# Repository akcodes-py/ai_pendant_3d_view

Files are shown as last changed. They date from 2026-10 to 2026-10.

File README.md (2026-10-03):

# Brain2 AI Pendant - 3D Interactive Web Viewer & CAD Architecture

An interactive, high-fidelity 3D web viewer and parametric CAD assembly model for the **Brain2 Wearable AI Pendant** prototype built with an octagonal cardboard enclosure and a 3-tier Starboard (perfboard) stacked core.

🌐 **Live 3D Web Viewer**: [https://akcodes-py.github.io/ai_pendant_3d_view/](https://akcodes-py.github.io/ai_pendant_3d_view/)  
📁 **Local File**: Open [`ai_pendant_3d_viewer.html`](ai_pendant_3d_viewer.html) or [`index.html`](index.html) in any browser.

---

## 🌟 Key Features

- **Realistic Electronic Component Rendering**:
  - **ESP32-S3 DevKit**: Rendered with dark PCB traces, gold header pins, silver metal RF shield, micro-USB connector, and silkscreen markings.
  - **INMP441 I2S MEMS Microphone**: Purple PCB with golden circular acoustic MEMS port positioned on the **upper side** facing the front sound pinhole for crystal-clear voice pickup.
  - **MicroSD Card Adapter**: Deep blue PCB, stainless-steel push-push card socket, and partially inserted microSD card facing the side cutout for easy card swapping.
  - **MT3608 5V Step-Up Boost Converter**: Rendered with copper toroidal ferrite inductor coil and precision multi-turn trimmer potentiometer.
  - **TP4056 Battery Charger**: Blue PCB with USB-C connector facing the side wall cutout.
  - **800mAh Li-Po Battery**: Silver metallic vacuum-sealed pouch cell with yellow Kapton insulation tape and silicone power lead wires.
  - **Starboard Perfboards**: Double-sided gold donut solder pads at standard $2.54\text{ mm}$ pitch.
- **Dual Front Controls & Indicator**:
  1. **5mm Blue Indicator LED**: Located at upper-center ($Y=72\text{ mm}$).
  2. **Round Voice Push Button Switch**: Located at mid-center ($Y=46\text{ mm}$) for thumb voice recording trigger.
  3. **White Push-Push Latching Power Switch**: Located at lower-center ($Y=24\text{ mm}$). Features white nylon stepped collar, round plunger, and dual horizontal solder tabs. Latches down on click (ON) and springs up on click (OFF) to cut battery power.
  4. **Upper-Side Microphone Sound Pinhole**: Located on the top-left shoulder ($Y=74\text{ mm}$) with golden bezel ring.
- **Interactive Controls Simulator**:
  - **Click White Power Switch**: Plunger physically latches down in 3D (ON) and energizes the circuit & Blue LED; clicking again pops it up (OFF) and cuts power.
  - **Press Voice Button**: Depresses the 3D button and activates **`RECORDING AUDIO`** mode with a pulsing Blue LED.
- **Vertical Layer Explosion Slider**:
  - Drag the slider from $0\text{ mm}$ (fully assembled) to $75\text{ mm}$ (exploded view) to pull apart all 3 Starboard decks and cardboard covers in mid-air.
- **Layer Isolation Filtering**:
  - Isolate and inspect any individual plate or starboard deck with zero clutter.

---

## 📐 Measured Component Dimensions (Hand Scale)

| Component Name | Length (cm) | Breadth (cm) | Height (cm) | Converted ($L \times W \times H$) | Stack Deck |
| :--- | :---: | :---: | :---: | :---: | :--- |
| **INMP441 MEMS Mic** | 1.4 | 1.1 | 0.35 | **$14 \times 11 \times 3.5\text{ mm}$** | **Deck 1 (Top / Front)** |
| **MicroSD Card Adapter** | 5.0 | 2.5 | 1.0 | **$50 \times 25 \times 10\text{ mm}$** | **Deck 1 (Top / Front)** |
| **ESP32-S3 DevKit** | 7.0 | 3.9 | 1.0 | **$70 \times 39 \times 10\text{ mm}$** | **Deck 2 (Middle)** |
| **Boost Converter (3V→5V)** | 4.5 | 2.3 | 1.5 | **$45 \times 23 \times 15\text{ mm}$** | **Deck 3 (Bottom / Power)** |
| **TP4056 Battery Charger** | 3.0 | 1.8 | 0.3 | **$30 \times 18 \times 3\text{ mm}$** | **Deck 3 (Bottom / Power)** |
| **800mAh Li-Po Battery** | 3.7 | 2.5 | 0.5 | **$37 \times 25 \times 5\text{ mm}$** | **Deck 3 (Bottom / Power)** |
| **White Latching Switch** | 0.8 | 0.8 | 0.7 | **$8 \times 8 \times 7\text{ mm}$** | **Deck 1 (Front Power)** |
| **Front Controls** | — | — | — | **$\varnothing 5\text{mm}$ LED, $\varnothing 7\text{mm}$ Button** | **Front Faceplate** |

---

## 🏗️ 3-Starboard Stack Architecture

```
┌────────────────────────────────────────────────────────┐
│  PLATE 1: FRONT CARDBOARD FACEPLATE (2.0 mm)           │
│  - Hole 1: 5mm Blue LED Dome (Ø5.0 mm at Y=72)         │
│  - Hole 2: Round Voice Push Button Cap (Ø7.0 mm at Y=46)│
│  - Hole 3: White Latching Switch Opening (Ø5.8 mm, Y=24)│
│  - Hole 4: Upper-Side Mic Sound Pinhole (Ø1.8 mm)      │
└────────────────────────────────────────────────────────┘
                           │
┌────────────────────────────────────────────────────────┐
│  PLATE 2: STARBOARD 1 (FRONT DECK: MIC + SD + CONTROLS)│
│  - INMP441 MEMS Mic on UPPER SIDE facing front hole    │
│  - MicroSD Card Adapter (50 × 25 × 10 mm) on side edge │
│  - 5mm Blue LED + Round Voice Button                   │
│  - White Latching Push-Push Power Switch with tabs     │
└────────────────────────────────────────────────────────┘
                           │  (8.4 mm Brass Standoffs)
┌────────────────────────────────────────────────────────┐
│  PLATE 3: STARBOARD 2 (MIDDLE DECK: ESP32-S3 CORE)     │
│  - ESP32-S3 DevKit (70 × 39 × 10 mm) centered         │
│  - Connects logic lines up to Deck 1 & power to Deck 3 │
└────────────────────────────────────────────────────────┘
                           │  (8.4 mm Brass Standoffs)
┌────────────────────────────────────────────────────────┐
│  PLATE 4: STARBOARD 3 (BOTTOM DECK: POWER SUBSYSTEM)   │
│  - MT3608 5V Step-Up Boost Converter (45 × 23 × 15 mm) │
│  - TP4056 Battery Charger (30 × 18 × 3 mm) with USB-C  │
│  - Li-Po 800mAh 3.7V Battery (37 × 25 × 5 mm)          │
└────────────────────────────────────────────────────────┘
                           │
┌────────────────────────────────────────────────────────┐
│  PLATE 5: OCTAGONAL RIM (34 mm) & BACK COVER (2.0 mm)  │
│  - Dual side cutouts: USB-C charging + MicroSD slot   │
│  - Top strain relief bracket + Neck lanyard cord       │
└────────────────────────────────────────────────────────┘
```

---

## ⚡ Electrical Connections & Pinout

```
[ 800mAh Li-Po Battery (3.7V) ]
            │
            ▼
[ TP4056 USB-C Charger (BAT+ / BAT-) ]
            │
    (White Latching Switch) ──> Intercepts positive rail via horizontal side solder tabs
            │
            ▼
[ MT3608 DC-DC Step-Up Converter (IN+ / IN-) ]
    • Input: 3.7V - 4.2V DC
    • Trimmed Output: Exactly 5.0V DC (OUT+ / OUT-)
            │
            ▼
[ Main 5.0V & GND Power Bus on Starboards ]
    ├──> ESP32 DevKit 5V Pin (Internal 3.3V LDO powers ESP32 core)
    ├──> MicroSD Card Adapter VCC (5V)
    ├──> INMP441 MEMS Mic VDD (3.3V pin from ESP32)
    └──> 5mm Blue LED (Anode to GPIO 2 via 220Ω, Cathode to GND)
```

---

## 🚀 How to Run Locally

1. Clone this repository:
   ```bash
   git clone https://github.com/akcodes-py/ai_pendant_3d_view.git
   cd ai_pendant_3d_view
   ```
2. Open [`index.html`](index.html) or [`ai_pendant_3d_viewer.html`](ai_pendant_3d_viewer.html) in any modern browser.

---

## 📄 License
MIT License. Created for the Brain2 Wearable AI Pendant prototype project.

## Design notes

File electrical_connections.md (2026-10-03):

# Brain2 AI Pendant - Complete Electrical Connections & Pinout Guide

## 1. Power Distribution Flow

```
[ 800mAh LiPo Battery (3.7V) ]
            │
            ▼
[ TP4056 USB-C Charger (BAT+ / BAT-) ]
            │
    (ON/OFF Slide Switch) ──> Intercepts positive rail between battery/charger and booster
            │
            ▼
[ MT3608 DC-DC Step-Up Converter (IN+ / IN-) ]
    • Input: 3.7V - 4.2V DC
    • Trimmed Output: Exactly 5.0V DC (OUT+ / OUT-)
            │
            ▼
[ Main 5.0V & GND Power Bus on Starboards ]
    ├──> ESP32 DevKit 5V Pin (Internal 3.3V LDO powers ESP32 core)
    ├──> MicroSD Card Adapter VCC (5V)
    ├──> INMP441 MEMS Mic VDD (3.3V pin from ESP32)
    └──> 5mm Blue LED (Anode to GPIO 2 via 220Ω, Cathode to GND)
```

---

## 2. Deck-by-Deck Wiring Pinout

### Deck 1: Starboard 1 (Front Deck — Mic + SD Card + Controls)

#### 1. INMP441 I2S MEMS Microphone (Upper-Side Placement)
| INMP441 Pin | ESP32-S3 Pin | Function / Description |
| :--- | :--- | :--- |
| **VDD** | **3V3** | 3.3V Clean logic power from ESP32 |
| **GND** | **GND** | System Ground |
| **SD** | **GPIO 32** | I2S Serial Data input |
| **WS (LRCLK)**| **GPIO 15** | Word Select (Left/Right clock) |
| **SCK (BCLK)**| **GPIO 14** | Bit Clock |
| **L/R** | **GND** | Left channel select |

#### 2. MicroSD Card Adapter (SPI Bus)
| MicroSD Pin | ESP32-S3 Pin | Function / Description |
| :--- | :--- | :--- |
| **VCC** | **5V Bus** | Powered from regulated 5.0V bus |
| **GND** | **GND** | Common Ground |
| **CS** | **GPIO 5** | Chip Select |
| **SCK** | **GPIO 18** | SPI Clock |
| **MOSI** | **GPIO 23** | SPI Master Out Slave In |
| **MISO** | **GPIO 19** | SPI Master In Slave Out |

#### 3. Front Controls (Two Buttons + Blue LED)
| Control | Connection 1 | Connection 2 | Notes |
| :--- | :--- | :--- | :--- |
| **Indicator Blue LED** | **GPIO 2** via **220Ω** resistor | **GND** | Illuminates when recording; idle heartbeat when standby |
| **Push Button** | **GPIO 0** (or GPIO 34) | **GND** | Momentary tactile switch with ESP32 internal pullup |
| **ON/OFF Slide Switch** | **TP4056 OUT+** | **MT3608 IN+** | Physical latching slide switch breaks the 3.7V battery circuit to turn the entire pendant ON and OFF |

---

### Deck 2: Starboard 2 (Middle Deck — ESP32-S3 DevKit)
- Centrally mounted with dual socket headers.
- **Top side**: Connects SPI bus, I2S bus, Button signal, and LED signal upward to Starboard 1.
- **Bottom side**: Receives +5V regulated power and GND upward from Starboard 3.

---

### Deck 3: Starboard 3 (Bottom Deck — Power Subsystem)
- **Battery**: Red wire (+) to TP4056 `B+`, Black wire (-) to TP4056 `B-`.
- **TP4056**:
  - `OUT+` routes to the **ON/OFF Slide Switch** on Deck 1.
  - `OUT-` connects directly to MT3608 `IN-` and common system ground.
- **MT3608 Boost Converter**:
  - `IN+`: Returns from the ON/OFF slide switch.
  - `OUT+`: Regulated **+5.00V DC** (preset with precision multi-turn trimmer screw before assembly).
  - `OUT-`: System ground bus.

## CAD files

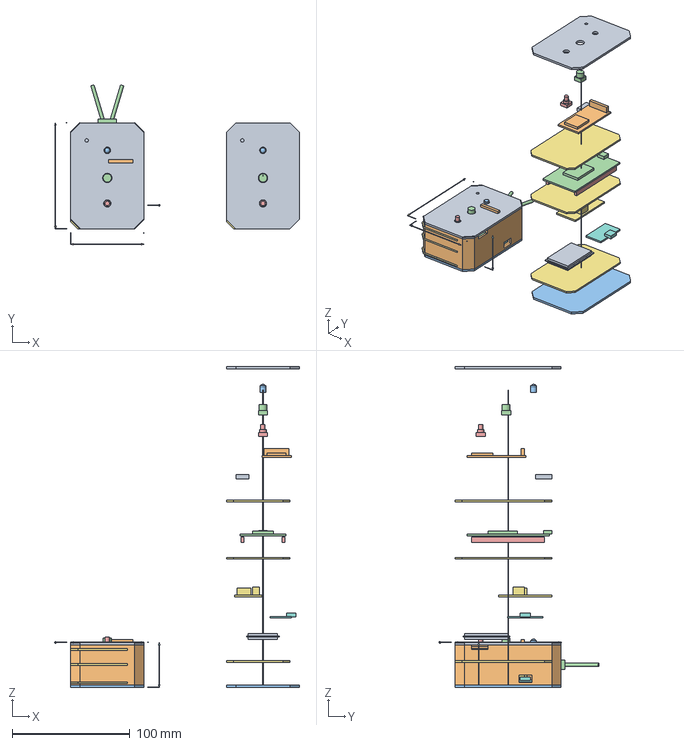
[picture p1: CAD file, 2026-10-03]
ai_pendant_mvp.step
207.8 x 136.0 x 272.2 mm

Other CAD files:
ai_pendant_mvp.FCStd
ai_pendant_mvp.stl

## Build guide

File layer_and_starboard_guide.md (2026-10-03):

# Brain2 AI Pendant - Dual Front Controls & 3-Starboard Architecture Guide

## 1. Front Controls & Acoustic Openings

The front side of the pendant now features all requested controls and sound ports:

| Front Element | Component Type | Coordinates / Location | Function & Wiring |
| :--- | :--- | :--- | :--- |
| **1. Indicator LED** | 5mm Blue Through-Hole LED | Upper Center ($Y=72\text{ mm}$) | Connected to ESP32 GPIO 2 via $220\,\Omega$ resistor. Shows Power ON, Recording, Wi-Fi. |
| **2. Push Button** | Round Tactile Push Button | Mid Center ($Y=46\text{ mm}$) | Connected to ESP32 GPIO 0 with internal pullup. Used for Voice Recording trigger / AI interaction. |
| **3. ON/OFF Power Switch** | Miniature Slide Switch | Lower Center ($Y=24\text{ mm}$) | Cuts power between Li-Po battery and MT3608 Boost Converter. Slides between ON and OFF positions. |
| **4. Upper MEMS Mic** | INMP441 I2S Microphone | Top-Left Shoulder ($Y=74\text{ mm}$) | Positioned on the upper side facing user's mouth with a $\varnothing 1.8\text{ mm}$ acoustic front pinhole. |

---

## 2. 3-Starboard Stacked Layer-by-Layer Placement

```
┌────────────────────────────────────────────────────────┐
│  PLATE 1: FRONT CARDBOARD FACEPLATE (2.0 mm)           │
│  - Precision cutouts for:                              │
│    1. Blue LED dome (Ø5.0 mm)                          │
│    2. Round Push Button cap (Ø7.0 mm)                  │
│    3. ON/OFF Slide Switch rectangular slot (8.5×4 mm) │
│    4. Upper Microphone sound pinhole (Ø1.8 mm)         │
└────────────────────────────────────────────────────────┘
                           │
┌────────────────────────────────────────────────────────┐
│  PLATE 2: STARBOARD 1 (FRONT DECK: MIC + SD + CONTROLS)│
│  - INMP441 MEMS Mic on UPPER SIDE facing front hole    │
│  - MicroSD Card Adapter (50 × 25 × 10 mm) on side edge │
│  - 5mm Blue LED + 220Ω resistor                        │
│  - Round Push Button Switch (Tactile momentary)        │
│  - ON/OFF Power Slide Switch (Latching power break)    │
└────────────────────────────────────────────────────────┘
                           │  (8.4 mm Brass Standoffs)
┌────────────────────────────────────────────────────────┐
│  PLATE 3: STARBOARD 2 (MIDDLE DECK: ESP32-S3 CORE)     │
│  - ESP32-S3 DevKit (70 × 39 × 10 mm) centered         │
│  - Dual header pin rows connecting signals to Deck 1   │
│    and regulated 5V power bus to Deck 3                │
└────────────────────────────────────────────────────────┘
                           │  (8.4 mm Brass Standoffs)
┌────────────────────────────────────────────────────────┐
│  PLATE 4: STARBOARD 3 (BOTTOM DECK: POWER SUBSYSTEM)   │
│  - MT3608 5V Step-Up Boost Converter (45 × 23 × 15 mm) │
│  - TP4056 Battery Charger (30 × 18 × 3 mm) with USB-C  │
│  - 800mAh 3.7V Li-Po Battery (37 × 25 × 5 mm)          │
└────────────────────────────────────────────────────────┘
                           │
┌────────────────────────────────────────────────────────┐
│  PLATE 5: OCTAGONAL RIM (34 mm) & BACK COVER (2.0 mm)  │
│  - Dual side cutouts: USB-C charging + MicroSD slot   │
│  - Top strain relief bracket + Neck lanyard cord       │
└────────────────────────────────────────────────────────┘
```

---

## 3. How to Use the 3D Viewer

1. Open your Desktop folder: `C:\Users\Atul Kumar\Desktop\brain2-pendant-cad`
2. Double-click **`ai_pendant_3d_viewer.html`** (or view the already opened browser window).
3. **Interactive Front Controls Testing**:
   - **Flip the ON/OFF Switch**: 
     - Slide to **OFF**: Circuit breaks! The Blue LED turns off, and the push button is disabled.
     - Slide to **ON**: Circuit energizes! The Blue LED illuminates, and the system is ready.
   - **Press the Push Button**:
     - While ON, click **Press Button**: The physical button in 3D depresses, and the Blue LED dome brightens and pulses with sound waves to indicate audio recording to the MicroSD card!
   - **Layer Explosion Slider**:
     - Drag the vertical slider to pull Starboard 1, Starboard 2, Starboard 3, and Cardboard covers apart in mid-air.

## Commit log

2026-10-03 Initial commit: Brain2 AI Pendant 3D viewer, 3-starboard CAD model, and documentation
    [ai_pendant_mvp.FCStd]
2026-10-03 Add STEP and STL 3D export models for ai_pendant_mvp
    [ai_pendant_mvp.step, ai_pendant_mvp.stl]
2026-10-03 Update power switch to physical white latching push-push button with side tabs matching hardware photo
    [ai_pendant_mvp.FCStd, ai_pendant_mvp.step, ai_pendant_mvp.stl]
2026-10-03 Add dual view choice: earlier solid assembled view vs photo FreeCAD model tree view with interactive eye visibility toggles, xray mode, and updated CAD exports
    [ai_pendant_mvp.FCStd, ai_pendant_mvp.step, ai_pendant_mvp.stl]
2026-10-03 Update push button to default ambient continuous recording with push-to-mute privacy and release/remove hand to resume recording
